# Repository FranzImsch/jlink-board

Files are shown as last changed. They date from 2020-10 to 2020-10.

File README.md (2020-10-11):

# Not A J-Link

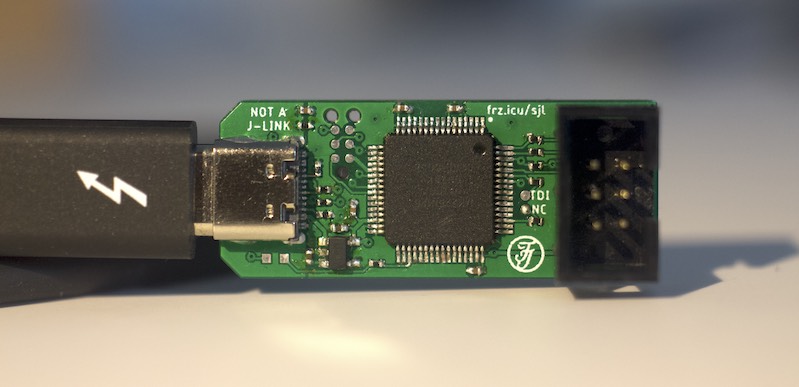
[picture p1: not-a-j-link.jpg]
overview


Replacement board for the J-Link EDU mini that features a power supply for the target device. It allows you to directly connect a programming probe or proper 2.54mm jumper wires without any adapters and it features a contemporary USB-C port. The chip on the board was carefully removed from a genuine J-Link, so its firmware is still original.

## Partlist

| Name | Part |
|---|---|
| C1, C2, C4, C5, C6  | 100nF 0402 |
| C8, C9 | 2.2µF 0402 |
| D1 | LED 0603 |
| R1, R2 | 5k1 0402 |
| R3, R4 | 33Ω 0402 |
| R7 | 10k 0402 |
| R8 | 220Ω 0402 |
| R9 - R13 | 150Ω 0402 |
| U$2 | TLV75533PDBVR (better: TLV75733PDBVR) |
| IC1 | MK22FN128VLH10 (MCU from J-Link) |
| J3 | 6P Box Header |
| J1 | USB-C or USB-A plug |

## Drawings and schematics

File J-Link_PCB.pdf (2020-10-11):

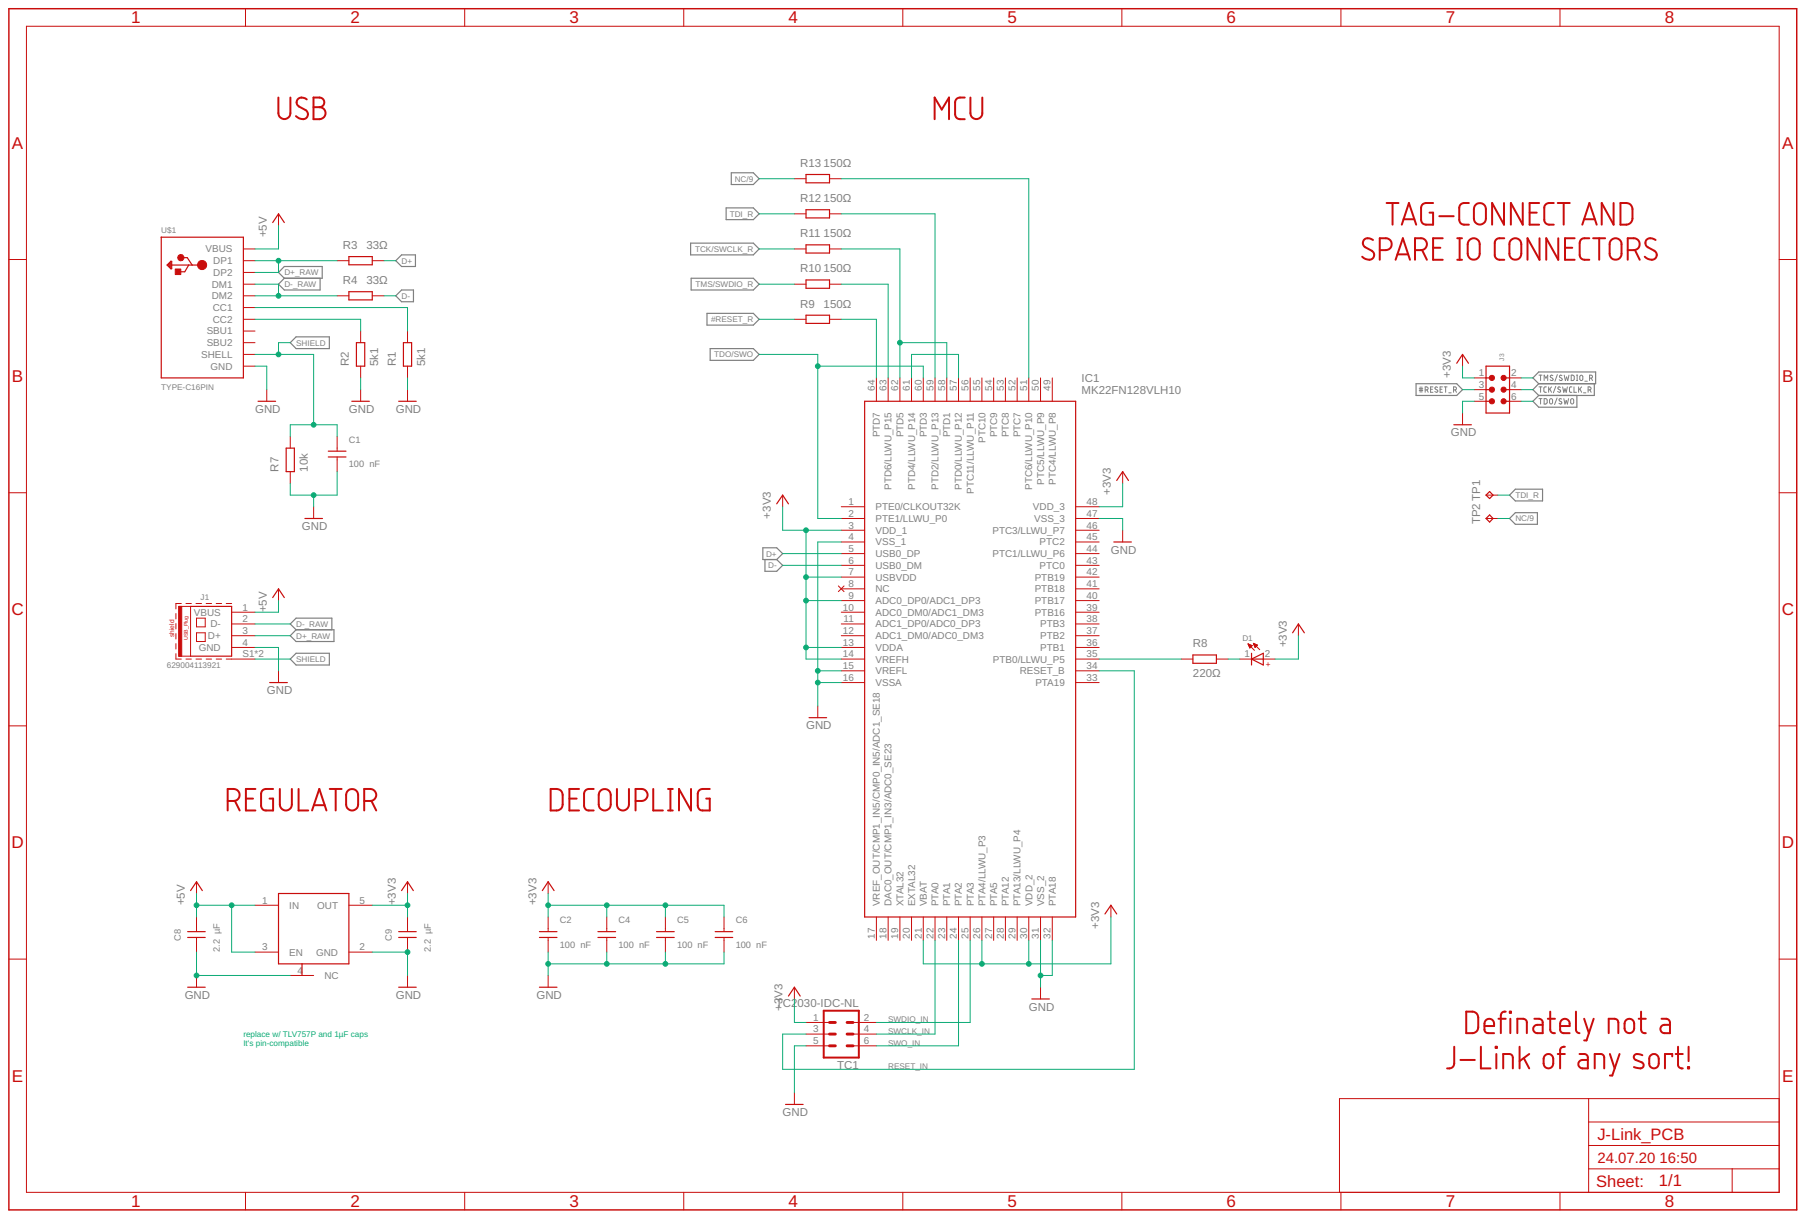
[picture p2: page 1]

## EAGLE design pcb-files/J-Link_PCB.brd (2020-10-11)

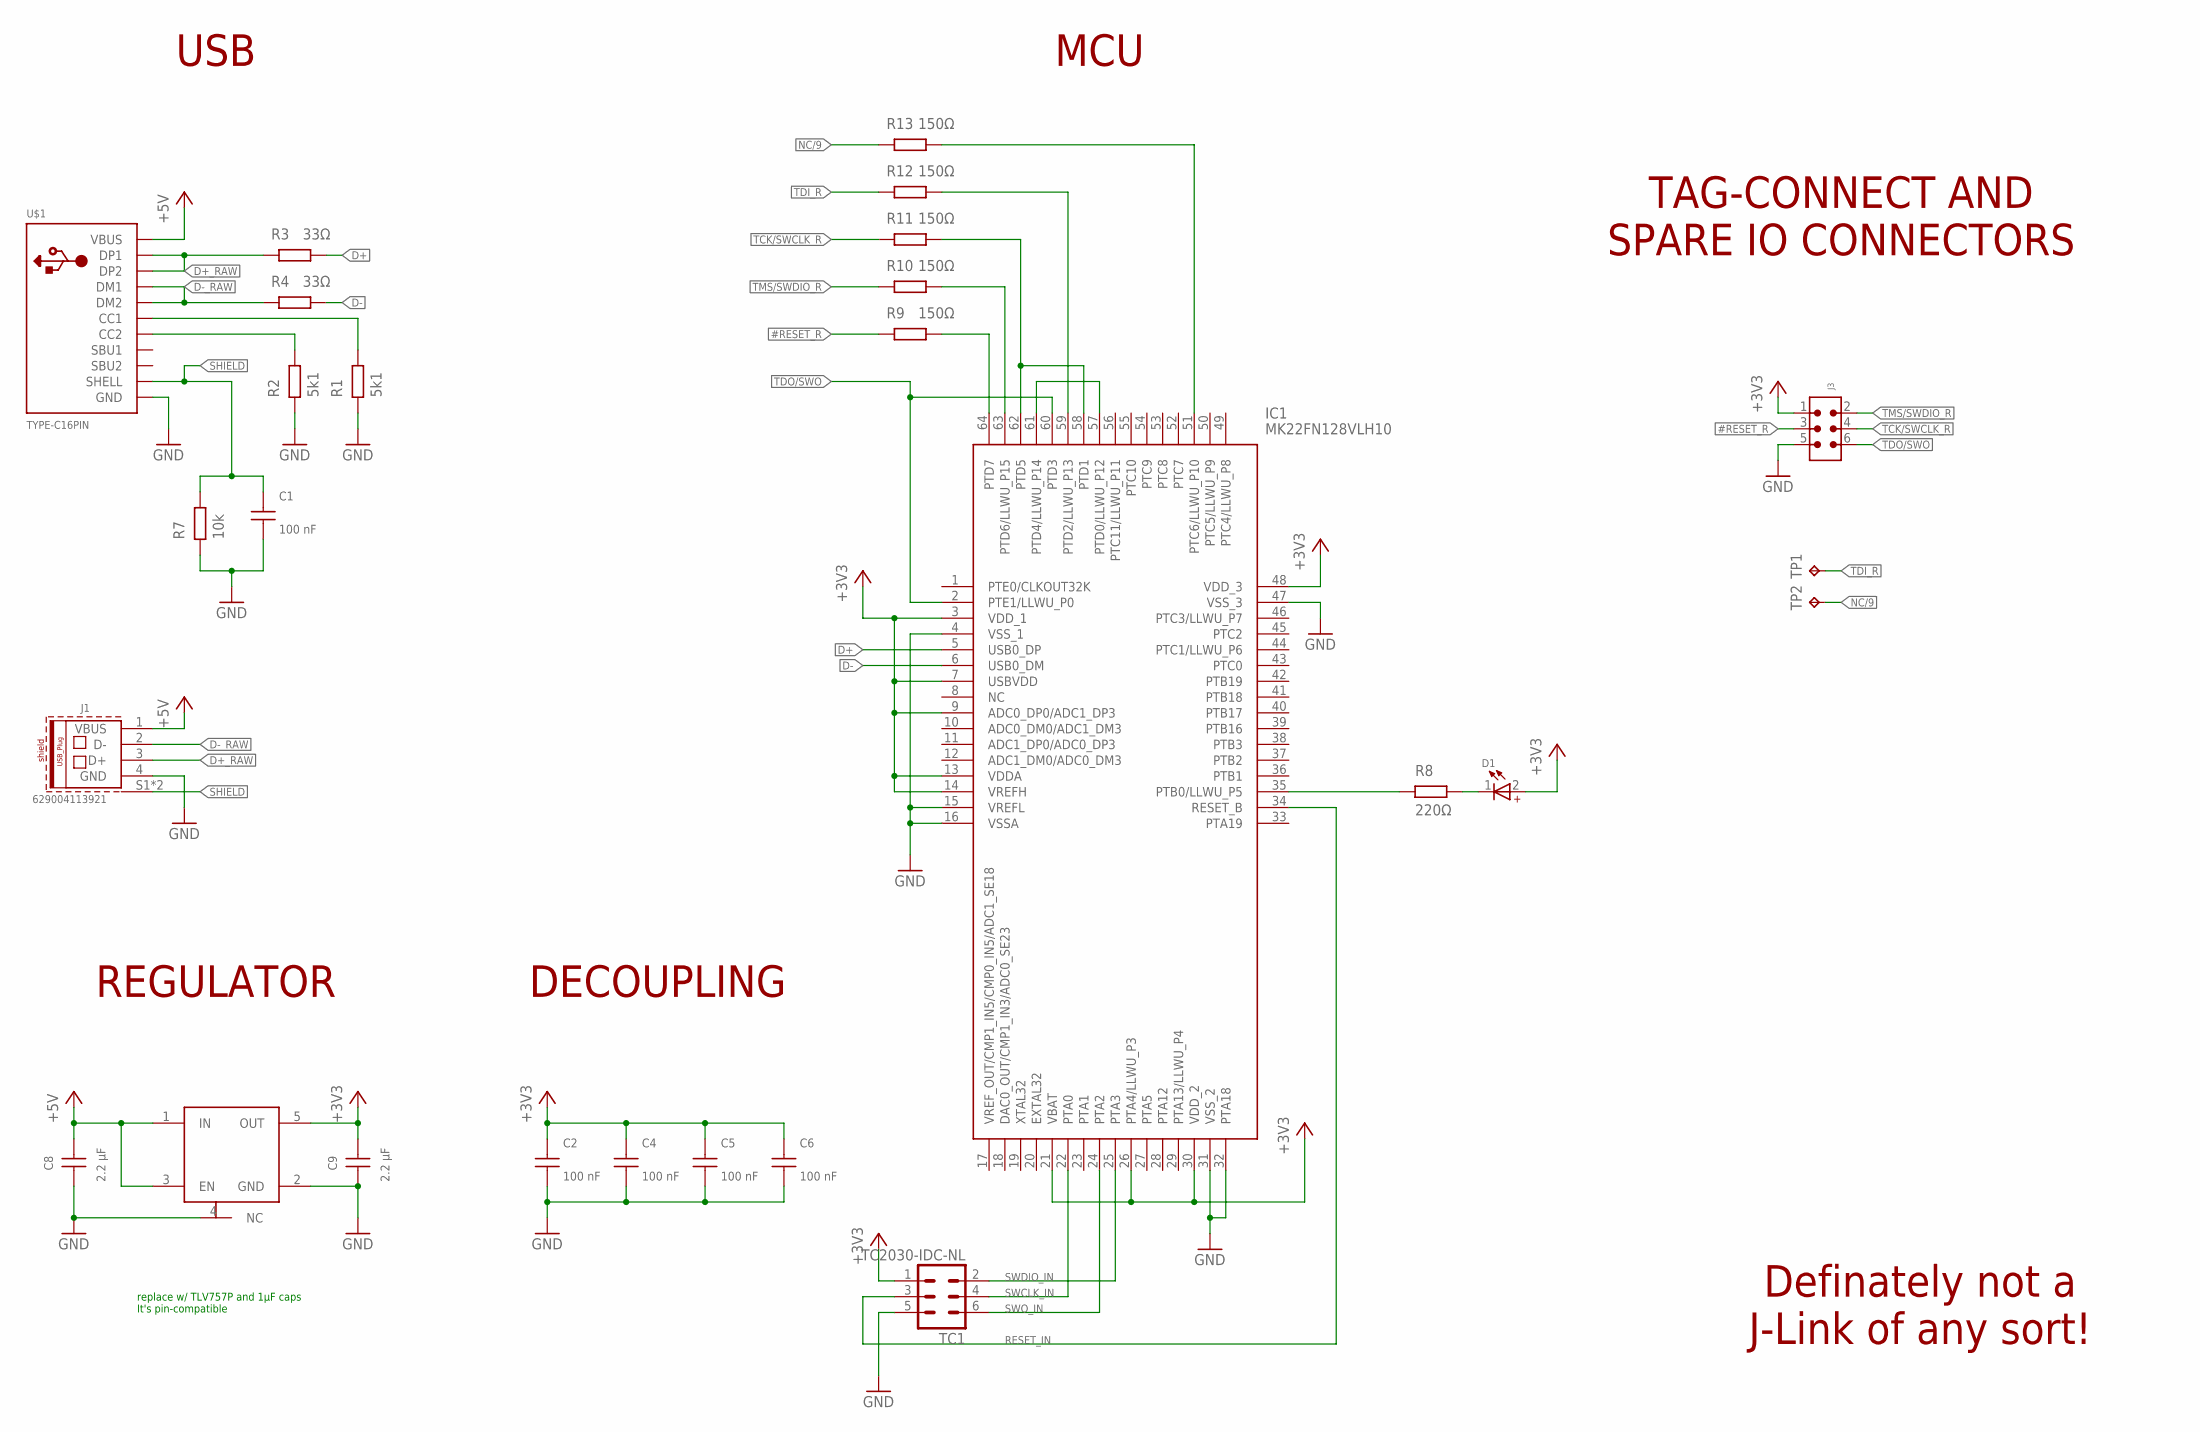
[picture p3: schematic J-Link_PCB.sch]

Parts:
C1, C2, C4, C5, C6: 100 nF; WCAP-CSGP_0402
C8, C9: 2.2 µF; WCAP-CSGP_0402
D1: WL-SMCW_0603_150060BS75000; WL-SMCW_0603
IC1: MK22FN128VLH10; QFP50P1200X1200X160-64N
J1: 629004113921
J3: 6120XX21621_61200621621; 61200621621
R1, R2: 5k1; WRIS-KSKE_0402
R3, R4: 33Ω; WRIS-KSKE_0402
R7: 10k; WRIS-KSKE_0402
R8: 220Ω; WRIS-KSKE_0402
R9, R10, R11, R12, R13: 150Ω; WRIS-KSKE_0402
TC1: TC2030-IDC-NL
TP1, TP2: TPTP09R; TP09R
U$1: TYPE-C16PIN
U$2: TLV75533PDBVRSOT-23-5; DBV_R-PDSO-G5

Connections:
#RESET: IC1.64 (PTD7), R9.2
#RESET_R: J3.3, R9.1
+3V3: C2.2, C4.2, C5.2, C6.2, C9.2, D1.2 (+), IC1.3 (VDD_1), IC1.7 (USBVDD), IC1.9 (ADC0_DP0/ADC1_DP3), IC1.13 (VDDA), IC1.14 (VREFH), IC1.21 (VBAT), IC1.26 (PTA4/LLWU_P3), IC1.30 (VDD_2), IC1.48 (VDD_3), J3.1, TC1.1, U$2.5 (OUT)
+5V: C8.2, J1.1 (VBUS), U$1.A4B9 (VBUS), U$1.B4A9 (VBUS), U$2.1 (IN), U$2.3 (EN)
D+: IC1.5 (USB0_DP), R3.2
D+_RAW: J1.3 (D+), R3.1, U$1.A6 (DP1), U$1.B6 (DP2)
D-: IC1.6 (USB0_DM), R4.2
D-_RAW: J1.2 (D-), R4.1, U$1.A7 (DM1), U$1.B7 (DM2)
GND: C1.1, C2.1, C4.1, C5.1, C6.1, C8.1, C9.1, IC1.4 (VSS_1), IC1.15 (VREFL), IC1.16 (VSSA), IC1.31 (VSS_2), IC1.32 (PTA18), IC1.47 (VSS_3), J1.4 (GND), J3.5, R1.1, R2.1, R7.1, TC1.5, U$1.A1B12 (GND), U$1.B1A12 (GND), U$2.2 (GND), U$2.4 (NC)
unnamed: R2.2, U$1.B5 (CC2)
unnamed: R1.2, U$1.A5 (CC1)
unnamed: IC1.59 (PTD2/LLWU_P13), R12.2
unnamed: IC1.58 (PTD1), IC1.62 (PTD5), R11.2
unnamed: IC1.57 (PTD0/LLWU_P12), IC1.61 (PTD4/LLWU_P14)
unnamed: IC1.51 (PTC6/LLWU_P10), R13.2
unnamed: IC1.35 (PTB0/LLWU_P5), R8.1
unnamed: D1.1 (-), R8.2
unnamed: IC1.63 (PTD6/LLWU_P15), R10.2
NC/9: R13.1, TP2.TP
RESET_IN: IC1.34 (RESET_B), TC1.3
SBU1: U$1.A8 (SBU1)
SBU2: U$1.B8 (SBU2)
SHIELD: C1.2, J1.S1 (SHIELD), J1.S2 (SHIELD), R7.2, U$1.SHELL1 (SHELL), U$1.SHELL2 (SHELL), U$1.SHELL3 (SHELL), U$1.SHELL4 (SHELL)
SWCLK_IN: IC1.22 (PTA0), TC1.4
SWDIO_IN: IC1.25 (PTA3), TC1.2
SWO_IN: IC1.24 (PTA2), TC1.6
TCK/SWCLK_R: J3.4, R11.1
TDI_R: R12.1, TP1.TP
TDO/SWO: IC1.2 (PTE1/LLWU_P0), IC1.60 (PTD3), J3.6
TMS/SWDIO_R: J3.2, R10.1

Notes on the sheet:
MCU
USB
REGULATOR
DECOUPLING
TAG-CONNECT AND SPARE IO CONNECTORS
Definately not a J-Link of any sort!
replace w/ TLV757P and 1µF caps It's pin-compatible

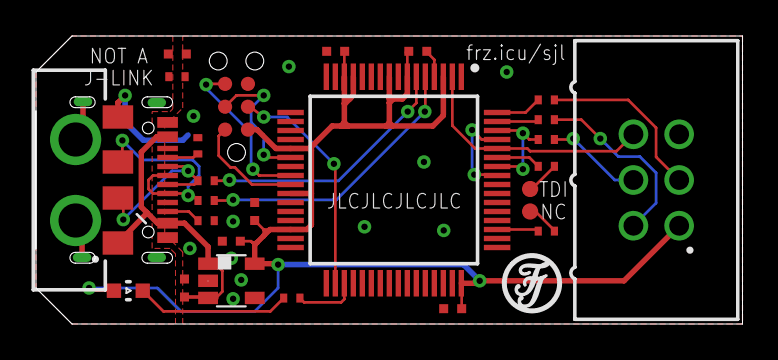
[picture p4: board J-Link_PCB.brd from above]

Board: 2 copper layers, 39.2 x 16.0 mm, 27 parts (0 on the bottom side), 28 nets.

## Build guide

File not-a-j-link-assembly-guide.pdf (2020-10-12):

Not-A-J-Link Assembly Guide

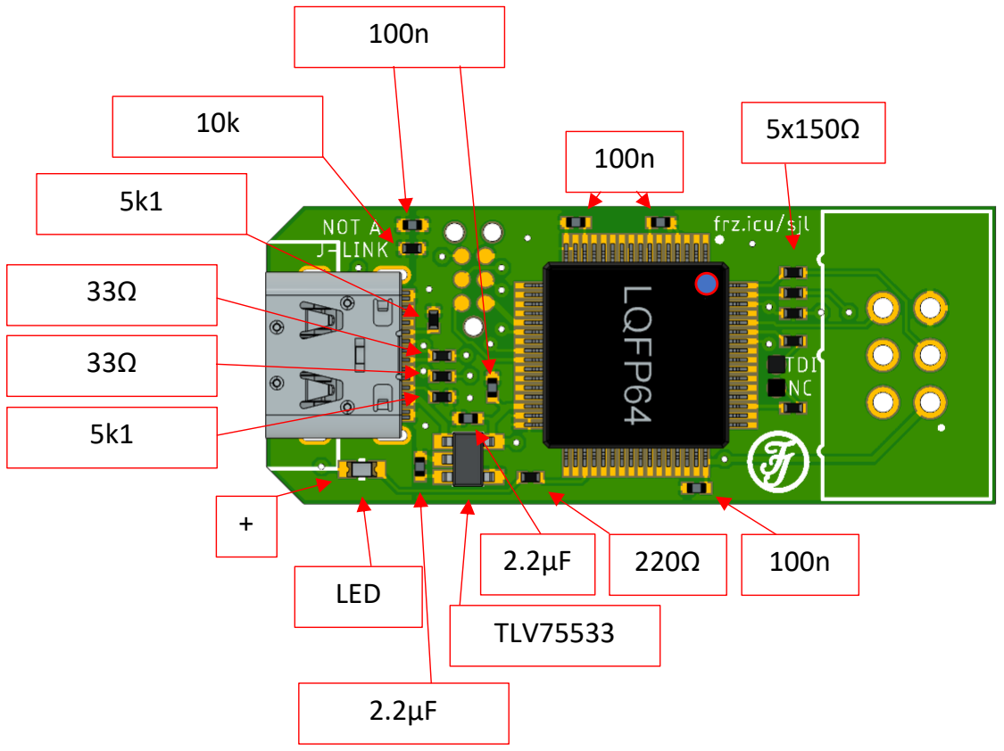
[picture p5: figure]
LED; TLV75533

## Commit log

2020-10-11 added files, fixed table in Readme
    [J-Link_PCB.brd, J-Link_PCB.sch]
2020-10-12 adding assembly guide

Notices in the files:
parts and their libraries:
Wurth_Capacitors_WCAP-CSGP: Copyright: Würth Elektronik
